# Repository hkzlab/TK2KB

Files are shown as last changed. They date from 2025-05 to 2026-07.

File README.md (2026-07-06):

# TK2KB

## DISCLAIMER

Any use of this project is **under your own responsibility**.
You will be responsible of checking the correct construction and functionality of your board.
By using this project You will agree that I cannot be held responsible if it will destroy any of your devices, damage your computer, burn down your house or whatever.

## Introduction

I recently built for myself a [TK2000 clone](https://github.com/clemarfolly/Microdigital-TK2000), but I don't have a keyboard to use it so,
before making an expensive mechanical one, I decided to test the design making one with some cheap SMD switches I had around.

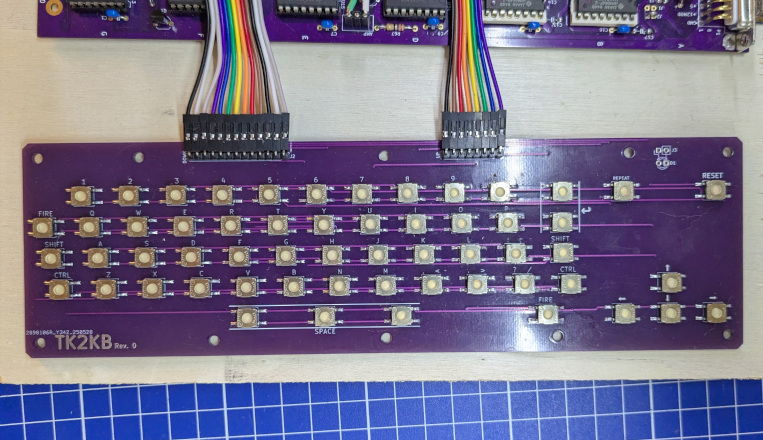
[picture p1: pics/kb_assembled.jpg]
Rev. 0 keyboard, assembled


## Hardware

The board was designed with [KiCad](https://kicad.org/) EDA.

### Bill of Materials

| Component | Qty | Type / Value | Notes |
| --- | --- | --- | --- |
| D1 |  1  | 3mm THT LED | Optional |
| J1 |  1  | 1x08 2.54mm, right angle pinheader | |
| J2 |  1  | 1x13 2.54mm, right angle pinheader | |
| J3 |  1  | 1x02 2.54mm, right angle pinheader | Optional |
| SW1-SW57 |  57 | SMD push buttons | KSC241G or compatible |

### Ordering the boards

You can order the board for this project at [PCBWay](https://www.pcbway.com/project/shareproject/TK2KB_TK2000_Keyboard_0d20454f.html) and support me or download 
the gerbers and have them printed wherever you like!!!

### 💰 Selling these boards 💰

I you want to contact me about selling this project, you can reach me via email at `0hkzUNDERSCOREprojects6ATposteoDOTnet` after properly fixing the email address by removing the digits and replacing the uppercase words with the proper characters.

**Contacts via other channels will be ignored**, as it means you did not read this document thoroughly.

"Collaborations" will boil down to the following:

- If you wish to produce and share this project at a loss or at cost, go for it. I am only asking for attribution and to let me know via email.
- If you want to do it for profit, let's discuss it. I'll probably settle for a rough 5% of the profit. Importing components is getting more expensive by the day, so this will contribute to me making future projects available for free.
- I will NOT do customer assistance for you or your customers. This is a hobby, not my job.

If this is not ok for you, you're cordially invited to go bother someone else :)

Authorized sellers will be listed in this README. If you find someone selling my boards without being listed here, it means they're stealing other people's work.

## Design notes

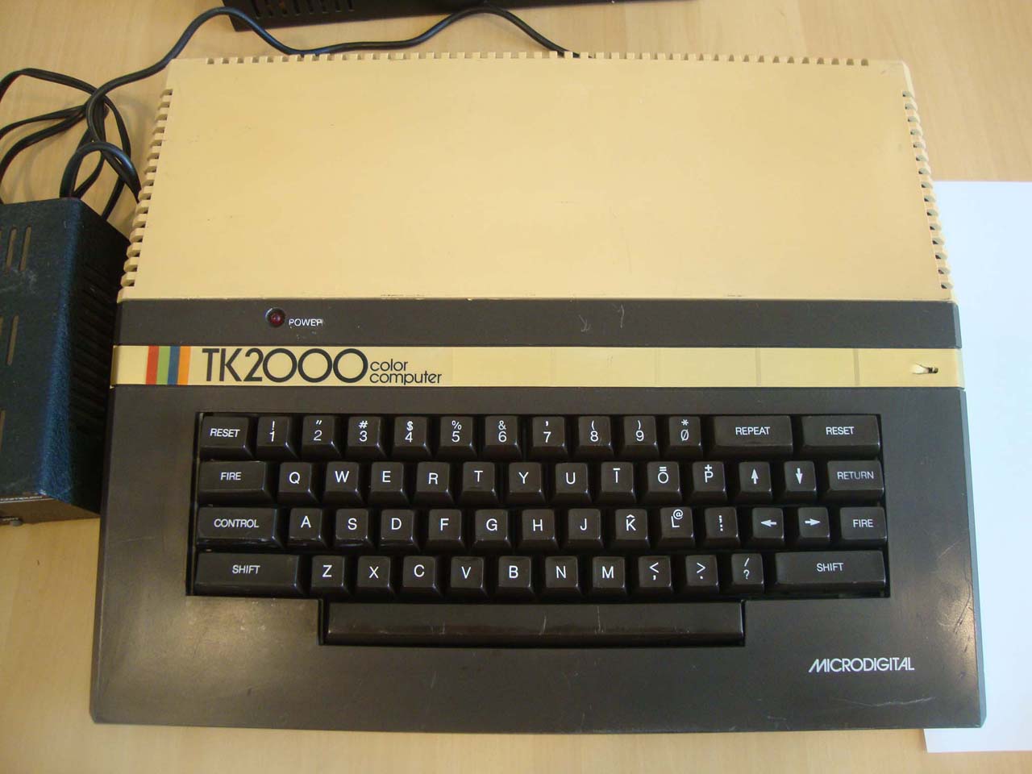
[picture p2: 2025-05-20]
pics/TK2000-3791205744.jpg

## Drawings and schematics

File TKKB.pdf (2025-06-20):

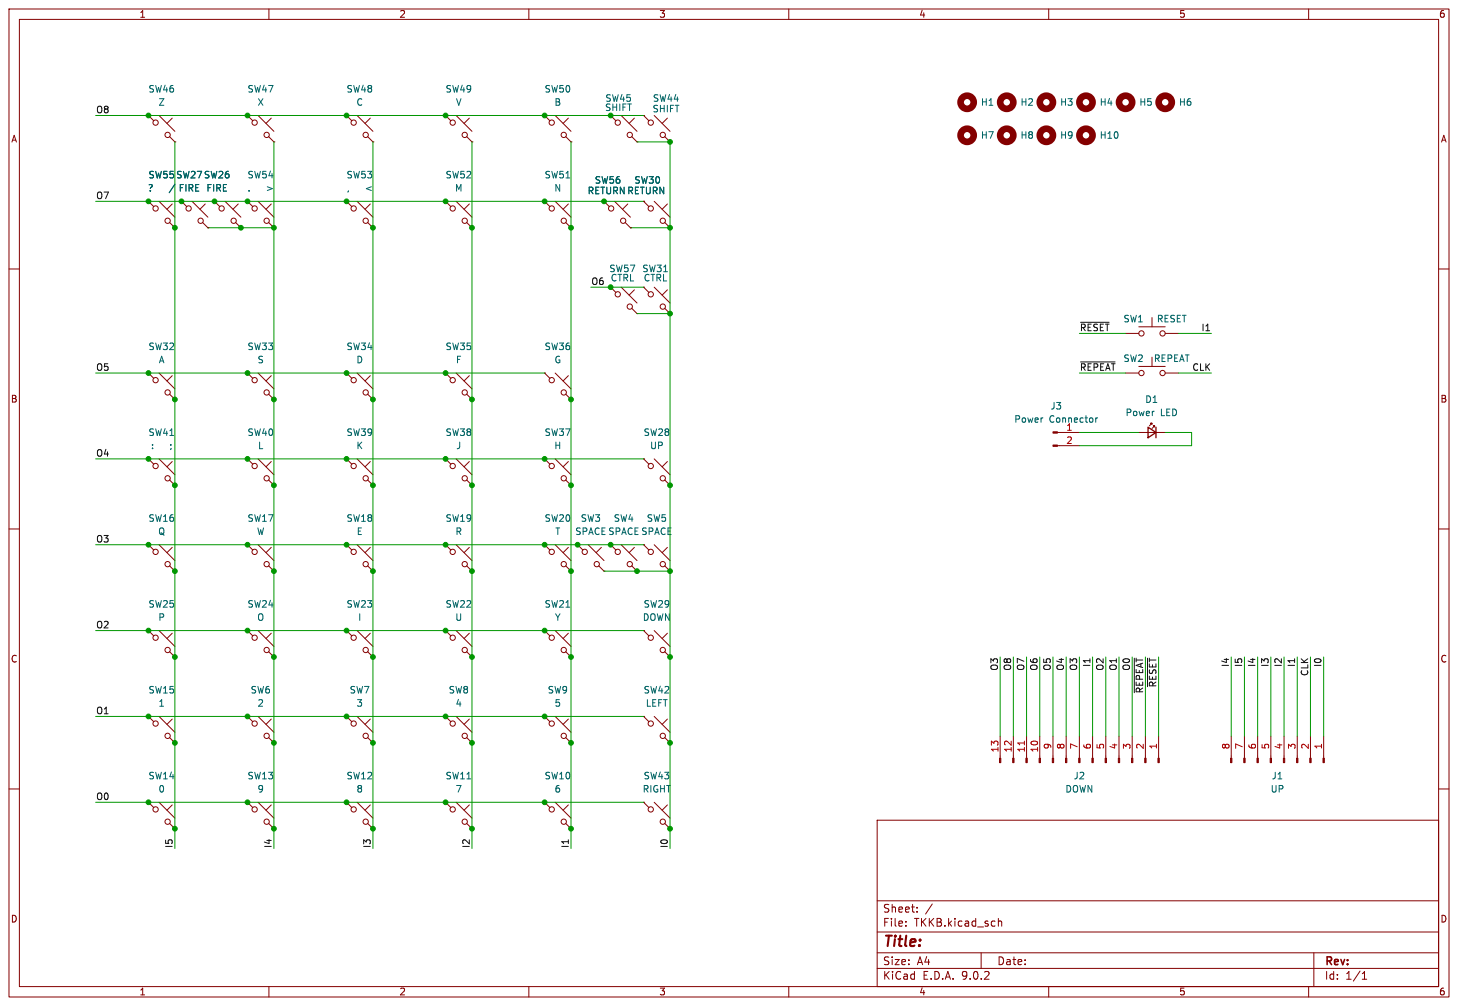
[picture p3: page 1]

Id: 1/1 Title: File: TKKB.kicad_sch Sheet: /

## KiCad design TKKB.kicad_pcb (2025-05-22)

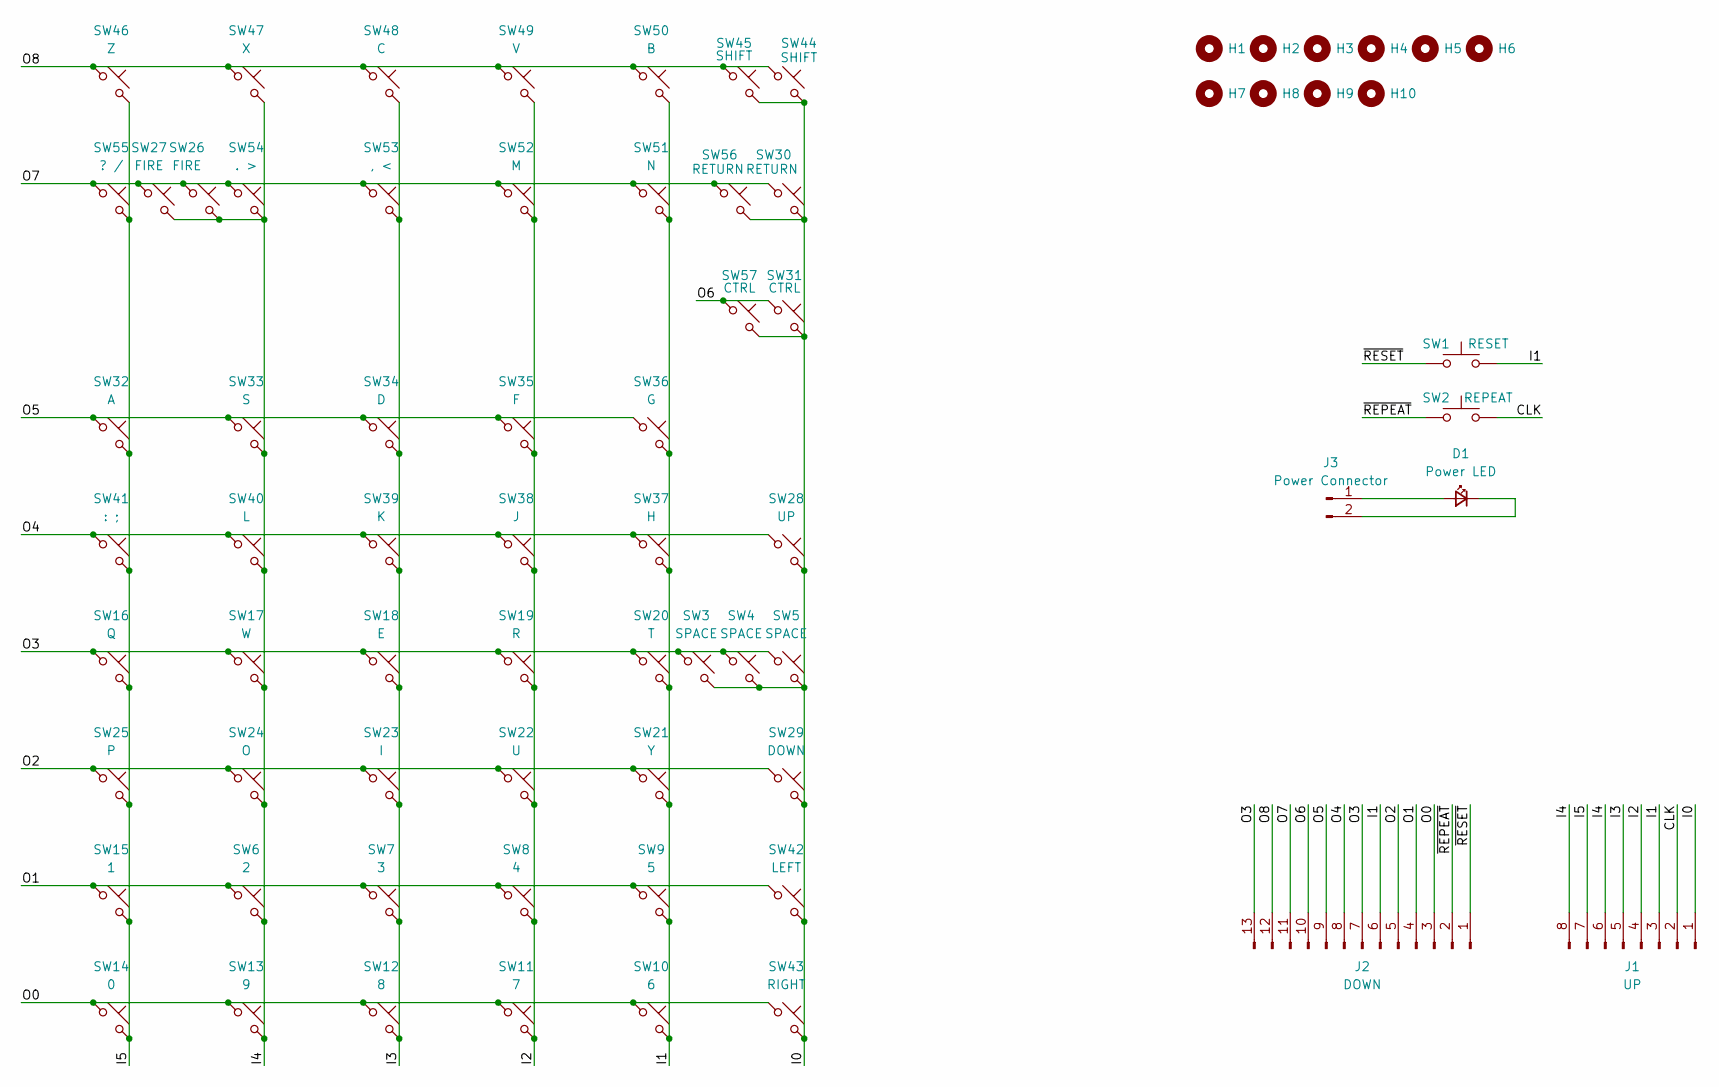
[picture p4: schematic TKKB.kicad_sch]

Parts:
D1: Power LED; LED_D3.0mm
H1, H2, H3, H4, H5, H6, H7, H8, H9, H10: MountingHole_Pad; MountingHole_3.2mm_M3_ISO7380
J1: UP; PinHeader_1x08_P2.54mm_Vertical
J2: DOWN; PinHeader_1x13_P2.54mm_Vertical
J3: Power Connector; PinHeader_1x02_P2.54mm_Vertical
SW1: RESET; SW_Push_SMD_Large
SW2: REPEAT; SW_Push_SMD_Large
SW3, SW4, SW5: SPACE; SW_Push_SMD_Large
SW6: 2; SW_Push_SMD_Large
SW7: 3; SW_Push_SMD_Large
SW8: 4; SW_Push_SMD_Large
SW9: 5; SW_Push_SMD_Large
SW10: 6; SW_Push_SMD_Large
SW11: 7; SW_Push_SMD_Large
SW12: 8; SW_Push_SMD_Large
SW13: 9; SW_Push_SMD_Large
SW14: 0; SW_Push_SMD_Large
SW15: 1; SW_Push_SMD_Large
SW16: Q; SW_Push_SMD_Large
SW17: W; SW_Push_SMD_Large
SW18: E; SW_Push_SMD_Large
SW19: R; SW_Push_SMD_Large
SW20: T; SW_Push_SMD_Large
SW21: Y; SW_Push_SMD_Large
SW22: U; SW_Push_SMD_Large
SW23: I; SW_Push_SMD_Large
SW24: O; SW_Push_SMD_Large
SW25: P; SW_Push_SMD_Large
SW26, SW27: FIRE; SW_Push_SMD_Large
SW28: UP; SW_Push_SMD_Large
SW29: DOWN; SW_Push_SMD_Large
SW30, SW56: RETURN; SW_Push_SMD_Large
SW31, SW57: CTRL; SW_Push_SMD_Large
SW32: A; SW_Push_SMD_Large
SW33: S; SW_Push_SMD_Large
SW34: D; SW_Push_SMD_Large
SW35: F; SW_Push_SMD_Large
SW36: G; SW_Push_SMD_Large
SW37: H; SW_Push_SMD_Large
SW38: J; SW_Push_SMD_Large
SW39: K; SW_Push_SMD_Large
SW40: L; SW_Push_SMD_Large
SW41: : ;; SW_Push_SMD_Large
SW42: LEFT; SW_Push_SMD_Large
SW43: RIGHT; SW_Push_SMD_Large
SW44, SW45: SHIFT; SW_Push_SMD_Large
SW46: Z; SW_Push_SMD_Large
SW47: X; SW_Push_SMD_Large
SW48: C; SW_Push_SMD_Large
SW49: V; SW_Push_SMD_Large
SW50: B; SW_Push_SMD_Large
SW51: N; SW_Push_SMD_Large
SW52: M; SW_Push_SMD_Large
SW53: , <; SW_Push_SMD_Large
SW54: . >; SW_Push_SMD_Large
SW55: ? /; SW_Push_SMD_Large

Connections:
/CLK: J1.2, SW2.2
/I0: J1.1, SW3.2, SW4.2, SW5.2, SW28.2, SW29.2, SW30.2, SW31.2, SW42.2, SW43.2, SW44.2, SW45.2, SW56.2, SW57.2
/I1: J1.3, J2.6, SW1.2, SW9.2, SW10.2, SW20.2, SW21.2, SW36.2, SW37.2, SW50.2, SW51.2
/I2: J1.4, SW8.2, SW11.2, SW19.2, SW22.2, SW35.2, SW38.2, SW49.2, SW52.2
/I3: J1.5, SW7.2, SW12.2, SW18.2, SW23.2, SW34.2, SW39.2, SW48.2, SW53.2
/I4: J1.6, J1.8, SW6.2, SW13.2, SW17.2, SW24.2, SW26.2, SW27.2, SW33.2, SW40.2, SW47.2, SW54.2
/I5: J1.7, SW14.2, SW15.2, SW16.2, SW25.2, SW32.2, SW41.2, SW46.2, SW55.2
/O0: J2.3, SW10.1, SW11.1, SW12.1, SW13.1, SW14.1, SW43.1
/O1: J2.4, SW6.1, SW7.1, SW8.1, SW9.1, SW15.1, SW42.1
/O2: J2.5, SW21.1, SW22.1, SW23.1, SW24.1, SW25.1, SW29.1
/O3: J2.7, J2.13, SW3.1, SW4.1, SW5.1, SW16.1, SW17.1, SW18.1, SW19.1, SW20.1
/O4: J2.8, SW28.1, SW37.1, SW38.1, SW39.1, SW40.1, SW41.1
/O5: J2.9, SW32.1, SW33.1, SW34.1, SW35.1, SW36.1
/O6: J2.10, SW31.1, SW57.1
/O7: J2.11, SW26.1, SW27.1, SW30.1, SW51.1, SW52.1, SW53.1, SW54.1, SW55.1, SW56.1
/O8: J2.12, SW44.1, SW45.1, SW46.1, SW47.1, SW48.1, SW49.1, SW50.1
/~REPEAT: J2.2, SW2.1
/~RESET: J2.1, SW1.1
unnamed: D1.2 (A), J3.1
unnamed: D1.1 (K), J3.2

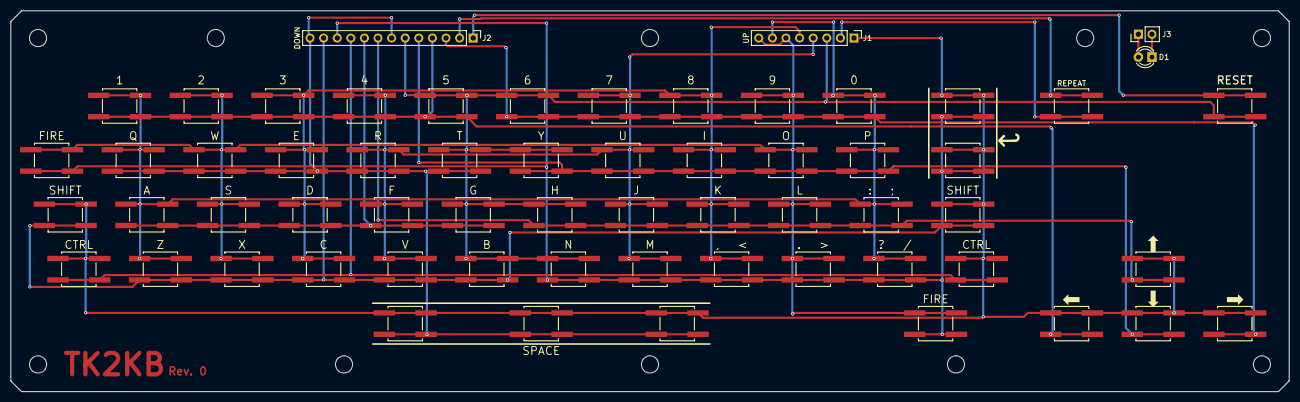
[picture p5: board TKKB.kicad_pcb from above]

Board: 2 copper layers, 238.8 x 71.1 mm, 71 parts (0 on the bottom side), 20 nets.

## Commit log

2025-05-20 Begin working on TK2000 keyboard
    [TKKB.kicad_pcb, TKKB.kicad_sch]
2025-05-20 Add all keys to schematic
    [TKKB.kicad_sch]
2025-05-20 Completed drawing the keyboard matrix
    [TKKB.kicad_sch]
2025-05-20 Begin drawing PCB
    [TKKB.kicad_pcb, TKKB.kicad_sch]
2025-05-21 Created the base keyboard
    [TKKB.kicad_pcb, TKKB.kicad_sch]
2025-05-21 Update silkscreen
    [TKKB.kicad_pcb]
2025-05-21 Add measurements
    [TKKB.kicad_pcb]
2025-05-22 Add silkscreen for every key
    [TKKB.kicad_pcb, TKKB.kicad_sch]
2025-05-22 Add rev.0 gerbers
    [TKKB.kicad_pcb]
2025-05-22 Add more stand holes for the keyboard
    [TKKB.kicad_pcb, TKKB.kicad_sch]
2025-06-20 Add readme, picture and schematics
2025-06-20 Add PCBWay link
